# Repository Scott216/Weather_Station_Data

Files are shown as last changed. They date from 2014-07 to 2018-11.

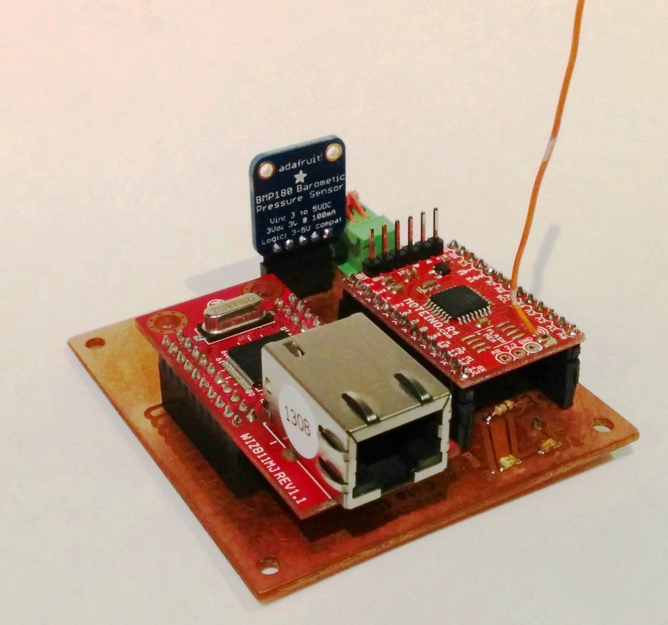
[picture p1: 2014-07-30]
Pics/Weather Data Uploader 2.jpg

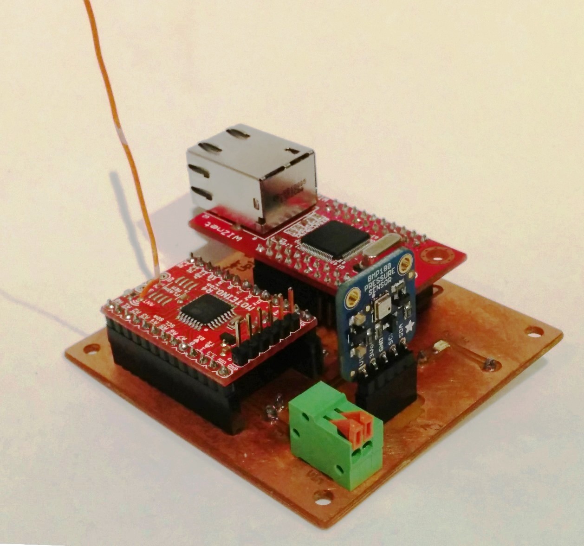
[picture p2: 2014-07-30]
Pics/Weather Data Uploader 1.jpg

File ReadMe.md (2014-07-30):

This project received Davis VantagePro wireless weather station data and sends to to Weather Underground's personal weather station (PWS).
It uses as Moteino (Arduino Uno + radio transceiver), WIZ811MJ Ethernet module and BMP180 pressure sensor <br>
See the [wiki](https://github.com/Scott216/Weather_Station_Data/wiki) for details.

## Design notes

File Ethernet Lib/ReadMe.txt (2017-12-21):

Modified Ethernet files.  You need to replace original Ethernet with the ones in this directory.
Original files are located:

Windows:
C:\Program Files(x86)\Arduino\libraries\Ethernet\
C:\Program Files(x86)\Arduino\libraries\Ethernet\utility\ 

Mac:
/Applications/Arduino.app (show pkg contents) /Contents/Resources/Java/libraries/Ethernet/src/ 
/Applications/Arduino.app (show pkg contents) /Contents/Resources/Java/libraries/Ethernet/src/utility/ 

Slave select modification by SurferTim.  See Arduino forum post
http://forum.arduino.cc/index.php?topic=217423.msg1601862#msg1601862

Use as follows:

#define SS_PIN 8
pinMode(SS_PIN, OUTPUT);
Ethernet.select(SS_PIN);
Ethernet.begin(mac, ip);

Info on disabling interrupts:
http://harizanov.com/2012/04/rfm12b-and-arduino-ethernet-with-wiznet5100-chip/

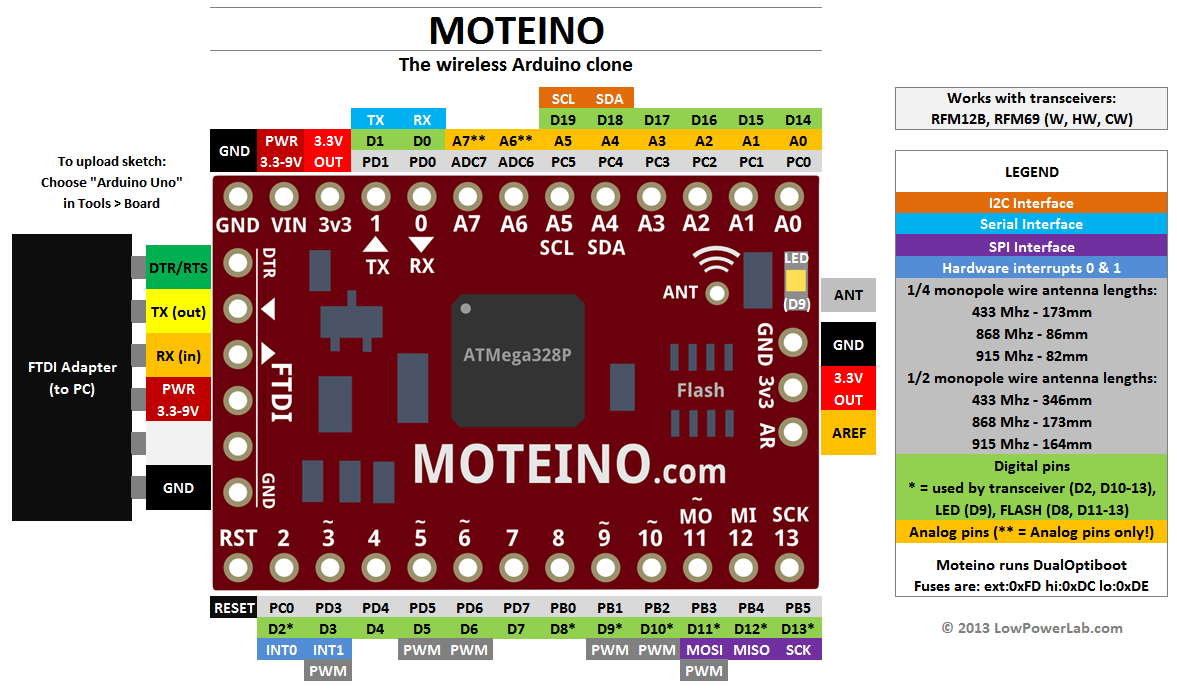
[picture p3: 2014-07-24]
Moteino Pinout.png

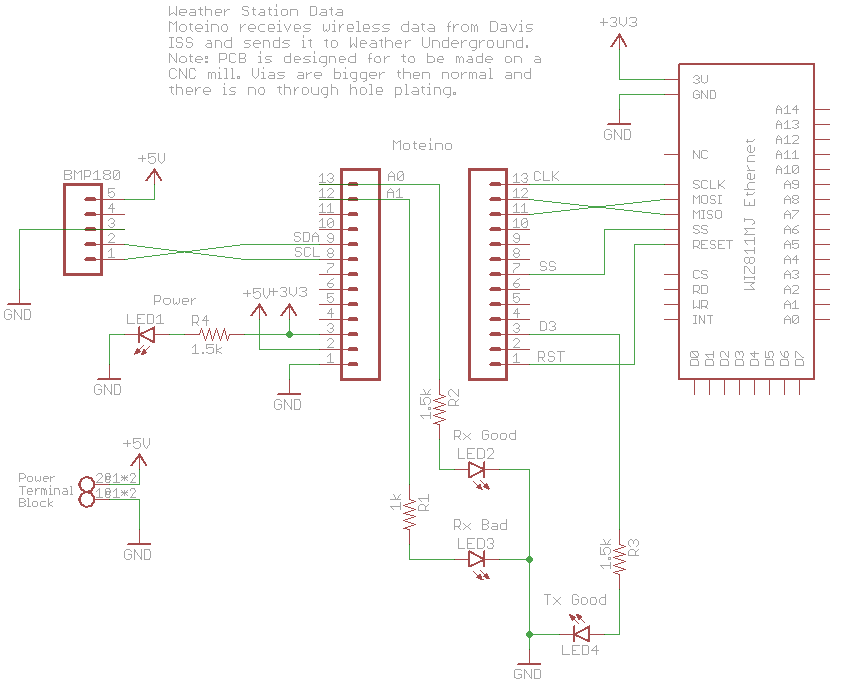
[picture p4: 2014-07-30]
Board Files/Weather Station Data v3.png

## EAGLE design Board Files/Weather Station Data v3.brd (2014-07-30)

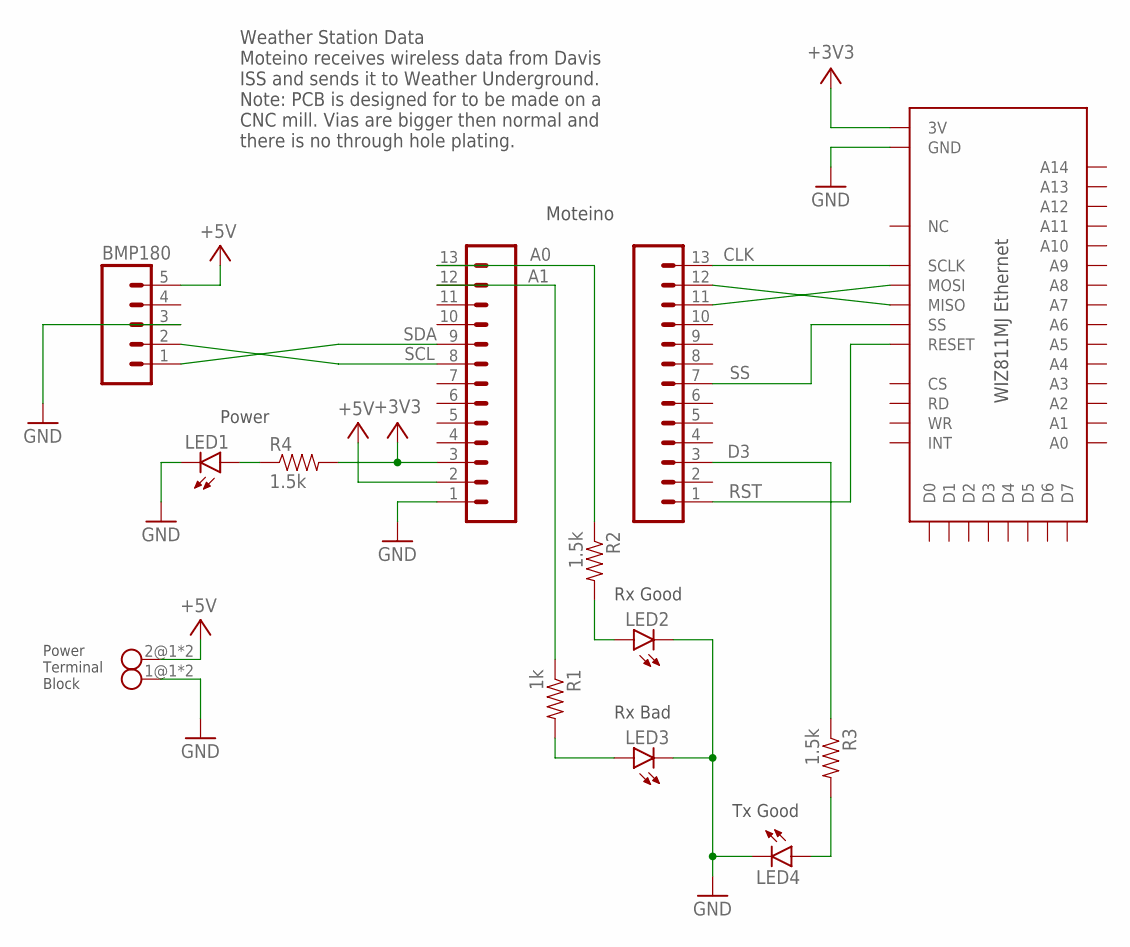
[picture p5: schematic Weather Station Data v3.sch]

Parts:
BMP180: M05PTH_LONGPADS; 1X05_LONGPADS
JP1, JP2: M13LONGPADS; 1X13-LONGPADS
LED1, LED2, LED4: 754-1440-1-ND; LED-1206
LED3: 754-1143-1-ND; LED-1206
POWER: SPRING_TB_RT2
R1: 1k; AXIAL-0.3
R2, R3, R4: 1.5k; AXIAL-0.3
U$1: WIZ811MJ

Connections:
+3V3: JP1.3, R4.P$2 (2), U$1.3V@1 (3V), U$1.3V@2 (3V)
+5V: BMP180.5, JP1.2, POWER.2@1, POWER.2@2
A0: JP1.13, R2.P$1 (1)
A1: JP1.12, R1.P$1 (1)
CLK: JP2.13, U$1.SCLK
D3: JP2.3, R3.P$1 (1)
GND: BMP180.3, JP1.1, LED1.C, LED2.C, LED3.C, LED4.C, POWER.1@1, POWER.1@2, U$1.GND@1 (GND), U$1.GND@2 (GND), U$1.GND@3 (GND), U$1.GND@4 (GND), U$1.GND@5 (GND)
MISO: JP2.12, U$1.MISO
MOSI: JP2.11, U$1.MOSI
unnamed: LED1.A, R4.P$1 (1)
unnamed: LED2.A, R2.P$2 (2)
unnamed: LED4.A, R3.P$2 (2)
unnamed: LED3.A, R1.P$2 (2)
RST: JP2.1, U$1.RESET
SCL: BMP180.2, JP1.8
SDA: BMP180.1, JP1.9
SS: JP2.7, U$1.SCS (SS)

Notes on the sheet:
Weather Station Data Moteino receives wireless data from Davis ISS and sends it to Weather Underground. Note: PCB is designed for to be made on a CNC mill. Vias are bigger then normal and there is no through hole plating.
Moteino
Power
Rx Good
Rx Bad
Tx Good
Power Terminal Block

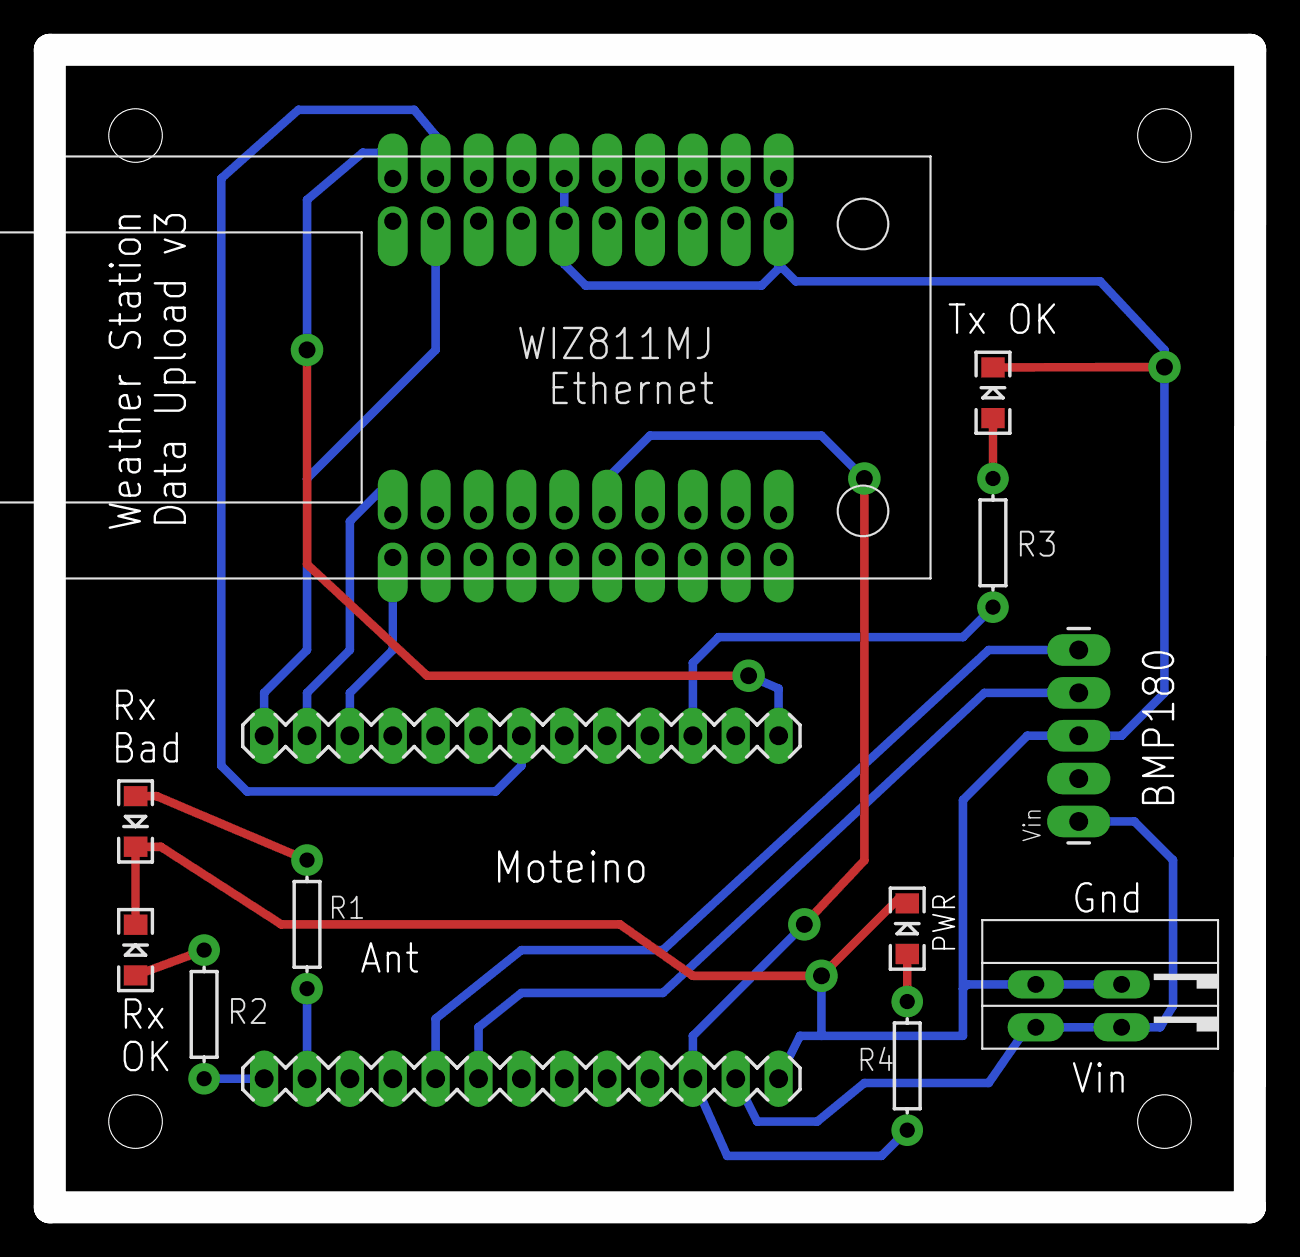
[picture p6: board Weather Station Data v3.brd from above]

Board: 2 copper layers, 71.1 x 68.6 mm, 13 parts (0 on the bottom side), 17 nets.

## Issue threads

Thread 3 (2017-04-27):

trouble adding OLED display

hjw, 2017-04-27:
Hi Scott,
I got your code up and running with an rfm69hcw breakout board and a redboard (UNO clone).. both from sparkfun. I commented out the ethernet and sensor related stuff and I can receive  data from my Davis station and print it out to the terminal console just fine.
I'd like to add a small (micro_OLED breakout, also sparkfun) also on the SPI bus to the mix and have it display some of the weather data, but I've had no luck doing this and can't figure out why.
All of my connections seem correct and I can 1) upload code which talks to the rfm69 fine, 2) upload code which talks to the OLED fine and 3) talks to both (I think), but then it hangs / doesn't connect to the weather station. I am not changing any wiring in order to test these 3 scenarios, simply the uploaded code.
In scenario 3 the display inits and outputs a test image and then the terminal/console prints out the debug text:
Weather Station v0.51
Using regular Moteino
Reboots = 48
Free mem: 1023

And then nothing, no "No new data from ISS...." messages, no hopCount increase messages (which I put in to try to track where things are hanging), nothing. The radio normally takes around 2 minutes to connect with the weather station for the first time but if I init the OLED along with the radio it's sat around for 20 minutes without getting past the initial debug text.
Any ideas? I'm using the default SS of 10 for the radio and pins
#define OLED_PIN_RESET 9
#define OLED_PIN_DC  8
#define OLED_PIN_CS  5
for the OLED.
Sincerely,
Hawley

Scott216, 2017-04-27:
I'm guessing that both the radio and OLED are using the same SS/CS pin (D10).  If that's the case, it's probably the cause of your lockup.   To fix it you would have to modify either the RFM library or OLED library to use a different pin - this may not be that easy to do.  If your OLED breakout supports I2C, I'd try using that instead of SPI.

hjw, 2017-04-27:
the radio is using ss/cs 10 and the OLED is using ss/cs 5.

Have you ever managed to add another component to the SPI bus along with the radio? All of the example of adding additional sensors etc add them to the I2C bus.

-Hawley

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

Scott216, 2017-04-27:
Yes, I use an Ethernet board on SPI, but I had to get someone to modify the Ethernet library so it would use a different SS pin.  But my setup does lock up about once a week - not sure why.  I'm planning on using an Moteino Mega which has a lot more memory to see if that helps.  One problem I have now is Weather Underground changed something on their servers and I can't send them data anymore.  I haven't had time to look into that issue.

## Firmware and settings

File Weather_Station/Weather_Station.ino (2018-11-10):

/*
Board type: 
Moteino 
To add Moteino to board list, in Arduino preferences, enter this URL
https://lowpowerlab.github.io/MoteinoCore/package_LowPowerLab_index.json

Changes to w5100 library so you can change slave select pin;
https://github.com/Scott216/Ethernet_SS_Mod



See Github repository for more information: http://git.io/Ds7oxw
Test weather station   http://www.wunderground.com/personal-weather-station/dashboard?ID=KVTDOVER3
Suntec weather station http://www.wunderground.com/personal-weather-station/dashboard?ID=KVTWESTD3

Weather Underground Wiki: http://wiki.wunderground.com/index.php/PWS_-_Upload_Protocol#GET_parameters

Issues:
Radio frequenlty has to re-sync frequency hopping timing - this can be slow

To Do:

To Try:
- Only get NTP time on startup
- Keep WDT going unless there is a CRC error. Radio data normally takes 2.5 seconds to get, which won't trigger WDT.  But when a CRC error comes in, data takes about 70 seconds to get
- Maybe usingInterrupt() can help https://www.arduino.cc/en/Reference/SPIusingInterrupt
- Also try using latest Ethernet and W5100.h libraries

 
I/O for Moteina 
A4,A5 - I2C communication with MPB180 sensor
A0 - Rx Good LED (green) - good packet received by Moteino
A1 - Rx Bad LED (red) - bad packet received by Moteino
D3 - Tx Good LED (green) - good upload to weather underground
D7 - Slave select for Ethernet module. For port registers, this is Port D, bit 7 on Moteino, not sure about MoteinoMega
D8 - Slave Select for Flash chip if  you got the Flash chip option on your Moteino
D9  LED mounted on the Moteino PCB 
D2, D10-13 - used by Moteino radio transciever. D10 is radio slave select


Change log:
07/23/14 v0.12 - Fixed isNewDay bug.  Averaged wind data and increased wind gust period to 5 minutes.  
07/24/14 v0.13 - Changed rainRate calculation, looks at 5 minutes instead on an hour, added station ID check
07/25/14 v0.14 - Enabled BPM180 for pressure and inside temp
07/28/14 v0.15 - Moved Tx Ok LED from D2 to D3.  D2 is used by transciever
07/29/14 v0.16 - Formatting changes,  removed printURL(), removed estOffset()
07/30/14 v0.17 - Added comments to help other users
08/06/14 v0.18 - Changed rain calculation from 5 minute buckets to 15 minute buckets
08/07/14 v0.19 - adjusted pressure for sea level, see http://bit.ly/1qYzlE6
08/22/14 v0.20 - Changed rain accumulation to assume ISS rain counter rolls over at 127, not 255
08/26/14 v0.21 - New rain rate calculation (testing)
08/27/14 v0.22 - Decoded packets for rain rate seconds, UV and Solar radiation.  Also changed ISS_... constants to only use MSB/
09/12/14 v0.23 - Changed rain calculation to calculate rate based on seconds between bucket tips
                 Added g_ prefix to global variables.  Removed averaging of current wind speed. Added smoothing algorithm for wind direction.
09/12/14 v0.24 - Removed last good packet timer.  Enabled rain rate calculation based on seconds between bucket tips
                 Moved packetBuffer & NTP_PACKET_SIZE from global variables to local.  These are passed as parameters to sendNTPpacket()
                 Changed upload time from 20 to 60 seconds.  Added pinMode() for the SS pin, use static ip instead of dynamic
09/14/14 v0.25 - Updated Ethernet.cpp library so I don't need pinMode() for the SS pin
10/04/14 v0.26 - Changed rain rate so it used data from ISS.
10/06/14 v0.27 - Added PRINT_DEBUG_WU_UPLOAD so I can only monitor Ethernet uploads and not fill serial monitor with other text
10/06/14 v0.28 - Get wind gust from ISS instead of calculating.  Changed Solar rad formula, but that's not used by me
10/07/14 v0.29 - Fixed bug in rain accumulation. Fixed wind speed bug in v.028
10/08/14 v.030 - Removed unused rain rate code.  Small general clean-up
10/14/14 v0.31 - Removed smoothing of wind direction, formula was invalid
10/15/14 v0.32 - Use vector averaging for wind direction
10/20/14 v0.33 - Changed wind direction formula to get rid of dead zone, see http://bit.ly/1uxc9sf
10/24/14 v0.34 - Tweaked rain rate formula based on results from last test and fixed wind direction rollover
11/29/14 v0.35 - Enabled internal pull-up resistors on SPI slave select pins
12/11/14 v0.36 - Added Reboot counter.
12/18/14 v0.37 - Made Moetino on board LED as a heartbeat
12/23/14 v0.38 - Made reboot counter in EEPROM an integer instead of a byte.  Redid output for PRINT_DEBUG.  Made it a tab delimited table. 
                 On startup get get daily rain accumulation from Weather Underground
12/31/14 v0.39 - Added 2 second delay after Udp.begin to see if it helped reduce serial monitor jibberish
                 Binary sketch size: 29,780 bytes (of a 32,256 byte maximum)
                 Free RAM 445 bytes
01/09/15 v0.40 - Moved reboot address to byte 2 because it wrote 1831 times to address 0
01/10/15 v0.41 - Changed WU Station ID to from test station (KVTDOVER3) to the real station (KVTWESTD3)
01/10/15 v0.42 - Changed getUtcTime() to getTime and added parameter to return UTC or EST time
                 Added WDT (watch dog timer) for WU uplaod.  Can't use it for the radio because radio takes over 8 seconds to lock onto channels
                 30,086 bytes, RAM 423 bytes
01/11/15 v0.43 - Fixed Hautespot (router needed reboot).  Switch this sketch back to test weather station
01/28/15 v0.44 - Added formula for PACKET_INTERVAL.  Changed millis() to micros()/1000 for lastRxTime timer (See: http://bit.ly/1HoH5Hn )  
01/31/15 v0.45 - Added windchill function
03/21/15 v0.46 - Added #ifdef to select MOTEINO_LED & SS_PIN_RADIO for Moteino or MoteinoMega
05/31/15 v0.47 - Added delay in soft reboot so text could print to serial monitor
07/08/15 v0.48 - Disabled getTodayRain(), redid NTP time so it tries twice for each NTP server
07/09/15 v0.49 - Changed processPacket() to decodePacket().  Changed getNtpTime to decodeNTPTime.  Changed getNewNtpTime to loop 3 times for each server
                 Changed getTime() to getFormattedTime()
                 Discovered problems I've been having were due to low battery in ISS tranmitter.  Changed transmitter ID from 3 to 1.
                 Changes to getTodayRain(). Added battery status and CRC errors to printData()
                 Since Hautewind seems dead, I disconnected it and have this sketch pushing data to that station ID
07/27/15 v0.50 - Sends message to serial monitor if no new data is coming through from ISS 
08/02/15 v0.51 - New Dekay RFM69 library. https://github.com/dekay/DavisRFM69
02/03/17 v0.52 - I think WU changed servers to AWS, now uploads don't work.  Fetching daily rain was returning huge numbers, so I set to zero if it's over 10 inches.  
                 Also added print statement when data is uploaded to WU
12/20/17 v0.53 - Changed how NTP works. Instead of using IP addresses for time server, using char timeServer[] = "time.nist.gov";  
12/21/17 v0.54 - Found forum post that explained GET request changes. https://forum.arduino.cc/index.php?topic=461649.msg3199335#msg3199335
12/21/17 v0.55 - Little bit of code cleanup, took out some of the debugging.  Switched back to main staion from test station.
12/22/17 v0.56 - Added #ifdef __AVR_ATmega328P__ to check for Moteino board type.  Compile Size: 28,596 bytes & 1584 bytes RAM
12/22/17 v0.57 - Tyring out kiwisincebrith's w5100.h/cpp files.  His version doesn't change Ethernet.h/cpp.  
                 Added print statement when getting invalid rain data from WU and textfinder. Compile size 28,556, 1582 dynamic (with only setup printing)
12/23/17 v0.58 - Added print statements to where WDT turns on and off to try and see where sketch is hanging.  
                 Modified getTodayRain() to print when textfinder fails. Added for loop to call getTodayRain() up to 10 times
                 Changed NTP time tries from 3 to 20 
12/24/17 v0.59 - Added PRINT_WEATHER_DATA to enable/disable printing weather data table.  Used to be part of PRINT_DEBUG    
12/28/17 v0.60 - Added print when hopCount is reset because it's too high.  Removed isNptTimeOk since I'm using now in upload 
                 Removed g_rainCounter and rainSeconds from printData()
01/11/18 v0.61 - Moved MAC and IP setup into #if defined that deteects Moteino Mega vs standard so IP and MAC are different
01/29/18 v0.62 - After 10 min WDT is not disabled during radio retrieval of data
01/29/18 v0.63 - Undid v0.62
*/

#define VERSION "v0.63" // Version of this program

#define PRINT_DEBUG     // Comment out to remove many of the Serial.print() statements
// #define PRINT_WEATHER_DATA // Prints weather data table.  Comment out to turn off
#define PRINT_DEBUG_WU_UPLOAD // Prints out messages related to Weather Underground upload. Comment out to turn off
#define PRINT_SETUP_INFO   // Prints which Moteino selected, reboots and free RAM from setip().  Comment out to turn off


#include <DavisRFM69.h>        // http://github.com/dekay/DavisRFM69
#include <Ethernet.h>          // Modified for user selectable SS pin and disables interrupts
#include <utility/W5100.h>     // Needed when using modified w5100.h files from kiwisincebirth
#include <EthernetUdp.h>       // http://github.com/arduino/Arduino/blob/master/libraries/Ethernet/src/EthernetUdp.h
#include <SPI.h>               // DavisRFM69.h needs this   http://arduino.cc/en/Reference/SPI
#include <Wire.h>              // http://github.com/arduino/Arduino/tree/master/libraries/Wire
#include <EEPROM.h>            // http://arduino.cc/en/Reference/EEPROM
#include "RTClib.h"            // http://github.com/adafruit/RTClib
#include "Adafruit_BMP085_U.h" // http://github.com/adafruit/Adafruit_BMP085_Unified
#include "Adafruit_Sensor.h"   // http://github.com/adafruit/Adafruit_Sensor
#include <TextFinder.h>        // http://playground.arduino.cc/Code/TextFinder (used in getTodayRain() from WU response)
#include <avr/wdt.h>           // Watchdog timeout.  Increases progam size by 64 bytes. I din't think it helps much
#include "Tokens.h"            // Holds Weather Underground password


// #define WUNDERGROUND_STATION_ID "KVTDOVER3" // Weather Underground station ID - test station
#define WUNDERGROUND_STATION_ID "KVTWESTD3" // Weather Underground station ID - normal station
const float ALTITUDE = 603.0;               // Altitude of weather station (in meters).  Used for sea level pressure calculation, see http://bit.ly/1qYzlE6
const byte TRANSMITTER_STATION_ID = 1;      // Davis ISS station ID to be monitored.  Default station ID is normally 1

// Reduce number of bogus compiler warnings, see http://bit.ly/1pU6XMe
#undef PROGMEM
#define PROGMEM __attribute__(( section(".progmem.data") ))

#if !defined(__time_t_defined)
  typedef unsigned long time_t;
#endif

// Header bytes from ISS (weather station tx) that determine what measurement is being sent
// Valid hex values are: 40 50 60 80 90 A0 E0  - really only care about MSB, the LSB is staion ID (where 0 is station #1)
// See http://github.com/dekay/im-me/blob/master/pocketwx/src/protocol.txt
//     http://bit.ly/1kDsXK4
//     http://www.wxforum.net/index.php?topic=10739.msg190549#msg190549
//     http://www.wxforum.net/index.php?topic=18489.msg178506#msg178506
#define ISS_UV_INDEX     0x4
#define ISS_RAIN_SECONDS 0x5
#define ISS_SOLAR_RAD    0x6
#define ISS_OUTSIDE_TEMP 0x8
#define ISS_WIND_GUST    0x9
#define ISS_HUMIDITY     0xA
#define ISS_RAIN         0xE

// char g_server [] = "weatherstation.wunderground.com";  // old WU server, still works, but use rtupdate instead
char g_server[] = "rtupdate.wunderground.com";  // Realtime update server - RapidFire
char g_API_server[] =  "api.wunderground.com";  // API server used to get WU data

// NTP Time Servers 
char g_timeServer1[] = "time.nist.gov";
char g_timeServer2[] = "utcnist.colorado.edu";



// Global variables used to store weather data that's sent to Weather Underground
byte     g_rainCounter =        0;  // rain data sent from outside weather station.  1 = 0.01".  Just counts up to 127 then rolls over to zero
byte     g_windgustmph =        0;  // Wind in MPH
float    g_dewpoint =         0.0;  // Dewpoint F
uint16_t g_dayRain =            0;  // Accumulated rain for the day in 1/100 inch
float    g_rainRate =           0;  // Rain rate in inches per hour
float    g_insideTemperature =  0;  // Inside temperature in tenths of degrees
int16_t  g_outsideTemperature = 0;  // Outside temperature in tenths of degrees
uint16_t g_barometer =          0;  // Current barometer in inches mercury * 1000
byte     g_outsideHumidity =    0;  // Outside relative humidity in %.
byte     g_windSpeed =          0;  // Wind speed in miles per hour
float    g_windDirection_Now =  0;  // Instantanious wind direction, from 1 to 360 degrees (0 = no wind data)
uint16_t g_windDirection_Avg =  0;  // Average wind direction, from 1 to 360 degrees (0 = no wind data)
bool     g_gotInitialWeatherData = false;  // flag to indicate when weather data is first received.  Used to prevent zeros from being uploaded to Weather Underground upon startup
bool     g_isBatteryOk = true;    // Battery status in ISS transmitter 

// I/O pins
const byte RX_OK =    A0;  // LED flashes green every time Moteino receives a good packet
const byte RX_BAD =   A1;  // LED flashes red every time Moteinoo receives a bad packet
const byte TX_OK =     3;  // LED flashed green when data is sucessfully uploaed to Weather Underground

const uint16_t UPLOAD_FREQ_SEC = 60; // Upload every 60 seconds
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
void loop()
{
  // Heartbeat LED
  static uint32_t heartBeatLedTimer = millis(); // Used to flash heartbeat LED
  if ( (long)(millis() - heartBeatLedTimer) > 200 )
  {
    digitalWrite(MOTEINO_LED, !digitalRead(MOTEINO_LED));
    heartBeatLedTimer = millis();
  }
  
  refreshNtpTime();  // refreshes NTP time every 100 minutes
  DateTime now = rtc.now();

  // Get wireless weather station data 
  bool haveFreshWeatherData = getWirelessData();
   
  // Send data to Weather Underground PWS.  Normally takes about 700mS
  static uint32_t uploadTimer = 0; // timer to send data to Weather Underground
  static uint32_t lastUploadTime = millis();  // Timestamp of last upload to Weather Underground.  Use for reboot if no WU uploads in a while.
  bool isTimeToUpload = (long)(millis() - uploadTimer) > 0;
  if( isTimeToUpload && haveFreshWeatherData && g_gotInitialWeatherData )
  {
    // Get data that's not from outside weather station - baramoter and inside temp
    g_dewpoint = dewPoint( (float)g_outsideTemperature/10.0, g_outsideHumidity);
    updateBaromoter();  
    updateInsideTemp();
    
    wdt_enable(WDTO_8S); // Turn watchdog on - only want it running for Ethernet upload.  Can't use it for radio because it would reset when frequency hopping
    Serial.print(F("WDT On "));
    Serial.println("1");
    if( uploadWeatherData() )       // Upload weather data
    { lastUploadTime = millis(); }  // If upload was successful, save timestamp
    wdt_disable(); 
    Serial.print(F("WDT Off "));
    Serial.println("2");
    
    uploadTimer = millis() + (UPLOAD_FREQ_SEC * 1000); // set timer to upload again in UPLOAD_FREQ_SEC seconds
  }
  else if ( isTimeToUpload && haveFreshWeatherData )
  {
    // sketch is not getting new data from radio, send message to serial monitor
    #ifdef PRINT_DEBUG
      char formatedDate[25];
      getFormattedTime(formatedDate, ESTZONE); 
      Serial.print(F("No new data from ISS, "));
      Serial.println(formatedDate); 
   #endif
  }
  
  // Reboot if millis is close to rollover. RTC_Millis won't work properly if millis rolls over.  Takes 49 days to rollover
  if( millis() > 4294000000UL )
  { softReset(); }

  // Reboot if no Weather Underground uploads in 30 minutes (1,800,000 mS) and  program is getting data from radio
  // If device isn't getting data from Davis ISS, then it's not supposed to upload to Weather Underground
  if( ((long)( millis() - lastUploadTime ) > 1800000L ) && haveFreshWeatherData )
  { 
    Serial.println(F("Reboot - No WU Upload"));
    delay(100);  // time to send text to serial monitor
    softReset(); 
  }
  
}  // end loop()


//=============================================================================
// Read wireless data coming from Davis ISS weather station
//=============================================================================
bool getWirelessData()
{
  static uint32_t lastRxTime = 0;  // timestamp of last received data.  Doesn't have to be good data
  static byte hopCount = 0;

  bool gotGoodData = false;  // Initialize
  
  // Process wireless ISS packet
  if ( radio.receiveDone() )
  {
    packetStats.packetsReceived++;
    // check CRC
    unsigned int crc = radio.crc16_ccitt(radio.DATA, 6);
    if ((crc == (word(radio.DATA[6], radio.DATA[7]))) && (crc != 0))
    {
      decodePacket();  
      packetStats.receivedStreak++;
      hopCount = 1;
      blink(RX_OK, 50);
      gotGoodData = true;
    }
    else
    {
      packetStats.crcErrors++;
      packetStats.receivedStreak = 0;
      blink(RX_BAD, 50);
      Serial.println(F("---Got CRC error")); // srg12 temp debug
    }
    
    // Whether CRC is right or not, we count that as reception and hop
    lastRxTime = micros()/1000UL;
    radio.hop();
  } // end if(radio.receiveDone())
  
  // If a packet was not received at the expected time, hop the radio anyway
  // in an attempt to keep up. Give up after 25 failed attempts. Keep track
  // of packet stats as we go. I consider a consecutive string of missed
  // packets to be a single resync. Thanks to Kobuki for this algorithm.
  // Formula for packet interval = (40 + STATION ID)/16 seconds.  ID is Davis ISS ID, default is 1 (which is 0 in packet data)
  // See: http://www.wxforum.net/index.php?topic=24981.msg240797#msg240797 
  // Dekay uses 2555 for Packet Interval, see: http://git.io/vqDqS
  const uint16_t PACKET_INTERVAL = (40.0 + TRANSMITTER_STATION_ID)/16.0 * 1000.0; 
  if ( (hopCount > 0) && (( (micros()/1000UL) - lastRxTime) > (hopCount * PACKET_INTERVAL + 200)) )
  {
    packetStats.packetsMissed++;
    if (hopCount == 1)
    { packetStats.numResyncs++; }
    
    if (++hopCount > 25)
    { 
      hopCount = 0; 
      Serial.println(F("---hopCount > 25")); // srg12 temporary debug
    }
    radio.hop();
  }
  
  return gotGoodData;
  
} // end getWirelessData()


//=============================================================================
// Received data and it passed CRC check.  This function decodes the weather data 
// Every packet contains wind speed, wind direction and battery status
// Packets take turns reporting other data
//=============================================================================
void decodePacket() 
{
  const byte SENSOR_OFFLINE = 0xFF;

  // Flags are set true as each variable comes in for the first time
  static bool gotTempData =     false;
  static bool gotHumidityData = false; 
  static bool gotRainData =     false;
  float       uvi =               0.0;  // UV index
  float       sol =               0.0;  // Solar radiatioin
  uint16_t    tt =                  0;  // Dummy variable for calculations
  uint16_t    rainSeconds =         0;  // seconds between rain bucket tips
  byte        byte4MSN =            0;  // Holds MSB of byte 4 - used for seconds between bucket tips

  // station ID - the low order three bits are the station ID.  Station ID 1 on Davis is 0 in this data
  byte stationId = (radio.DATA[0] & 0x07) + 1;
  if ( stationId != TRANSMITTER_STATION_ID )
  { return; }  // exit function if this isn't the station ID program is monitoring

  // Every packet has wind speed, wind direction and battery status in it
  g_windSpeed = radio.DATA[1];  

  // There is a dead zone on the wind vane. No values are reported between 8
  // and 352 degrees inclusive. These values correspond to received byte
  // values of 1 and 255 respectively
  // See http://www.wxforum.net/index.php?topic=21967.50
  //  float windDir = 9 + radio.DATA[2] * 342.0f / 255.0f; - formula has dead zone from 352 to 10 degrees
  if ( radio.DATA[2] == 0 )
  { g_windDirection_Now = 0; }
  else 
  { g_windDirection_Now = ((float)radio.DATA[2] * 1.40625) + 0.3; }  // This formula doesn't have dead zone, see: http://bit.ly/1uxc9sf
  avgWindDir(g_windDirection_Now);  // Average out the wind direction with vector math

  // 0 = battery ok, 1 = battery low.  
  if ( ((radio.DATA[0] & 0x8) >> 3) == 0 )
  { g_isBatteryOk = true; }
  else
  { g_isBatteryOk = false; }
  
  // Look at MSB in firt byte to get data type
  switch (radio.DATA[0] >> 4)
  {
  case ISS_OUTSIDE_TEMP:
    g_outsideTemperature = (int16_t)(word(radio.DATA[3], radio.DATA[4])) >> 4;
    gotTempData = true;  // one-time flag when data first arrives.  Used to track when all the data has arrived and can be sent to PWS  
    break;

  case ISS_HUMIDITY:
    // Round humidity to nearest integer
    g_outsideHumidity = (byte) ( (float)( word((radio.DATA[4] >> 4), radio.DATA[3]) ) / 10.0 + 0.5 );
    gotHumidityData = true;  // one-time flag when data first arrives
    break;
  
  case ISS_WIND_GUST:
    g_windgustmph = radio.DATA[3];
    break;
      
  case ISS_RAIN: 
    g_rainCounter = radio.DATA[3];
    if ( g_initialRainReading == NO_READING )
    { g_initialRainReading = FIRST_READING; } // got first rain reading
    else if ( g_initialRainReading == FIRST_READING )
    { g_initialRainReading = AFTER_FIRST_READING; } // already had first reading, now it's everything after the first time
    gotRainData = true;   // one-time flag when data first arrives

    updateRainAccum();
    break;

  case ISS_RAIN_SECONDS:  // Seconds between bucket tips, used to calculate rain rate.  See: http://www.wxforum.net/index.php?topic=10739.msg190549#msg190549
    byte4MSN = radio.DATA[4] >> 4;
    if ( byte4MSN < 4 )
    { rainSeconds =  (radio.DATA[3] >> 4) + radio.DATA[4] - 1; }  
    else
    { rainSeconds = radio.DATA[3] + (byte4MSN - 4) * 256; }
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

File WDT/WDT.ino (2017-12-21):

// Use ATTiny 85 as watchdog timer

const uint32_t TIMEOUT_MIN = 10;  // Watchdog timeout in minutes
const byte HEARTBEAT_INPUT =  3;
const byte LED_RED =          0;  // connected tor Red/Green LED
const byte LED_GRN =          1; 
const byte RELAY =            2; // controls power to device being monitored
const uint32_t MINUTE =   60000;  // one minute for millis() timer

uint32_t g_heartbeat_time_high = 0;
uint32_t g_heartbeat_time_low =  0;


// Function prototypes
void rebootRemoveDevice();



void setup() 
{
  pinMode(HEARTBEAT_INPUT, INPUT);
  pinMode(LED_RED, OUTPUT);
  pinMode(LED_GRN, OUTPUT);
  pinMode(RELAY, OUTPUT);
  
  rebootRemoveDevice();
  
} // end setup()

void loop() 
{
  // Check high heartbeat
  if ( digitalRead(HEARTBEAT_INPUT) == HIGH )
  { g_heartbeat_time_high = millis(); }

  // Check low heartbeat
  if ( digitalRead(HEARTBEAT_INPUT) == LOW )
  { g_heartbeat_time_low = millis(); }

  // Need to get a high and low heartbeat
  bool  isOkHighHeartbeat = (long)(millis() - g_heartbeat_time_high) < (TIMEOUT_MIN * MINUTE);
  bool  isOkLowHeartbeat =  (long)(millis() - g_heartbeat_time_low)  < (TIMEOUT_MIN * MINUTE);
  if (!isOkHighHeartbeat || !isOkLowHeartbeat )
  {
    // turn on red LED
    digitalWrite(LED_RED, HIGH);
    digitalWrite(LED_GRN, LOW);

    digitalWrite(RELAY, LOW); // Turn relay off to power down monitored device
    delay(10000); // wait 10 seconds
    
    rebootRemoveDevice();  // Restore power
  }
  
  // Green LED should mimic the heartbeat input
  digitalWrite(LED_RED, LOW);
  digitalWrite(LED_GRN, digitalRead(HEARTBEAT_INPUT));
  
}  // end loop()

void rebootRemoveDevice()
{
  digitalWrite(RELAY, HIGH); // turn relay on
  
  // Turn LED yellow to indicate waiting in setup
  analogWrite(LED_RED, 127);
  analogWrite(LED_GRN, 127);
  delay(MINUTE * 5); // just wait here for five minutes
  
  // Turn LED off
  digitalWrite(LED_RED, LOW);
  digitalWrite(LED_GRN, LOW);
  
  // reset timers
  g_heartbeat_time_high = millis();
  g_heartbeat_time_low = millis();
  
}  // end rebootRemoveDevice()

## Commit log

2014-07-20 v0.1 - getting VSS data and can upload
    Gets VSS weather station data and can upload to Weather Underground
    test station. Don’t have barometer sensor yet and haven’t tested radio
    with upload yet.
2014-07-20 Modified Ethernet.h library
    This library lets user choose different slave select pin. Normally
    it’s D10.
2014-07-23 Interrupts work-around
    Disabled interrupts in w5100.cpp for setSS(), then re-enabled them in
    resetSS()
2014-07-23 V0.11 - working
    Working version. Don’t have pressure sensor hooked up yet
2014-07-29 v15 - moved Tx OK LED to D3, minor edits
2014-07-29 Modified Ethernet library files
    Added slave select ability and disabled interrupts
2014-07-30 Schematic and PCB Files
    [Weather Station Data v3.brd, Weather Station Data v3.sch]
2014-08-09 v0.19 fixed barometer calc
    Adjusted barometer for sea level
    [Weather_Station.ino]
2014-08-22 v0.20 fixed rain accum bug
    Davis ISS rain counter rolls over at 127, not 255 like I assumed. I
    also changed my station ID to 3
    [Weather_Station.ino]
2014-10-08 fixed pinMode bug
    Couldn’t use static IP because of a missing pinMode() for SS pin
    [Ethernet.cpp]
2014-10-17 v0.32 Fixed wind averaging
    [Weather_Station.ino]
2014-10-26 Fixed wind direction bug
    [Weather_Station.ino]
2014-12-23 v0.37 - See change log
    Adjusted rain rate formula, enabled pull-ups in SS pins, reboot
    counter, Heartbeat LED
    [Weather_Station.ino]
2014-12-24 v0.38 Redid print debug, read daily rain from WU
    Made reboot counter in EEPROM an integer instead of a byte. Redid
    output for PRINT_DEBUG. Made it a tab delimited table.
    On startup get get daily rain accumulation from Weather Underground
    [Weather_Station.ino]
2015-01-04 v0.39 minor tweaks
    Added 2 second delay after Udp.begin to see if it helped reduce serial
    monitor jibberish - didn’t help
    [Weather_Station.ino]
2015-01-30 Initial Commit
    These are DeKay’s RFM69 library files from early 2014
2015-01-30 v0.44 - packet interval change
    Changed packet interval from 2555 to formula. Change millis() to
    micros()/1000 because micros is more accurate
2015-01-30 Results of testing different packet intervals
    Increased interval for 1mS and every 10 minutes, then counted number of
    good packets received over the 10 minutes. Sketch ran for a couple
    days.
2015-01-30 Added MoteinoMega compatibility and some SPI changes
    Made changes so library would work with MoteinoMega
    - Added statement to insure slave select pin would be high
    - Slowed down SPI speed
    - Moved SPI.setDataMode(), SPI.setBitOrder(), SPI.setClockDivider from
    initialize() to interruptHandler()
    These changes reflect some of the changes in the LowPowerLabs RFM69
    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
2015-06-21 v0.47 - delay in reboot
    Needed delay in reboot so serial monitor could display message before
    Arduino rebooted.
    [Weather_Station.ino]
2017-12-21 Initial commit for WDT
    Code to use ATTiny as a watchdog timer. Haven’t tested it yet
2017-12-21 Initial commit to test which moteino board is being used.
    Can detect if it’s a MoteinoMega with __AVR_ATmega1284__
2017-12-21 v0.55 - fixed NTP problem and WU GET request format
    Changed NTP so it used a URL instead of IP addresses.
    March 2017 Weather Underground switched AWS and the get request format
    had to be updated.
    [Weather_Station.ino]
2017-12-22 v0.57 - got working again
    Changed NTP from IP to a url. Fixed updated GET request format -
    changed when Weather Underground moved to AWS servers.
    [Weather_Station.ino]
2017-12-23 Initial commit
    Schematic for MoteinoMega

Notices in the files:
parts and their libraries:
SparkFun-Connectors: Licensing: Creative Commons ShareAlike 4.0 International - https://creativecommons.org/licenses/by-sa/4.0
